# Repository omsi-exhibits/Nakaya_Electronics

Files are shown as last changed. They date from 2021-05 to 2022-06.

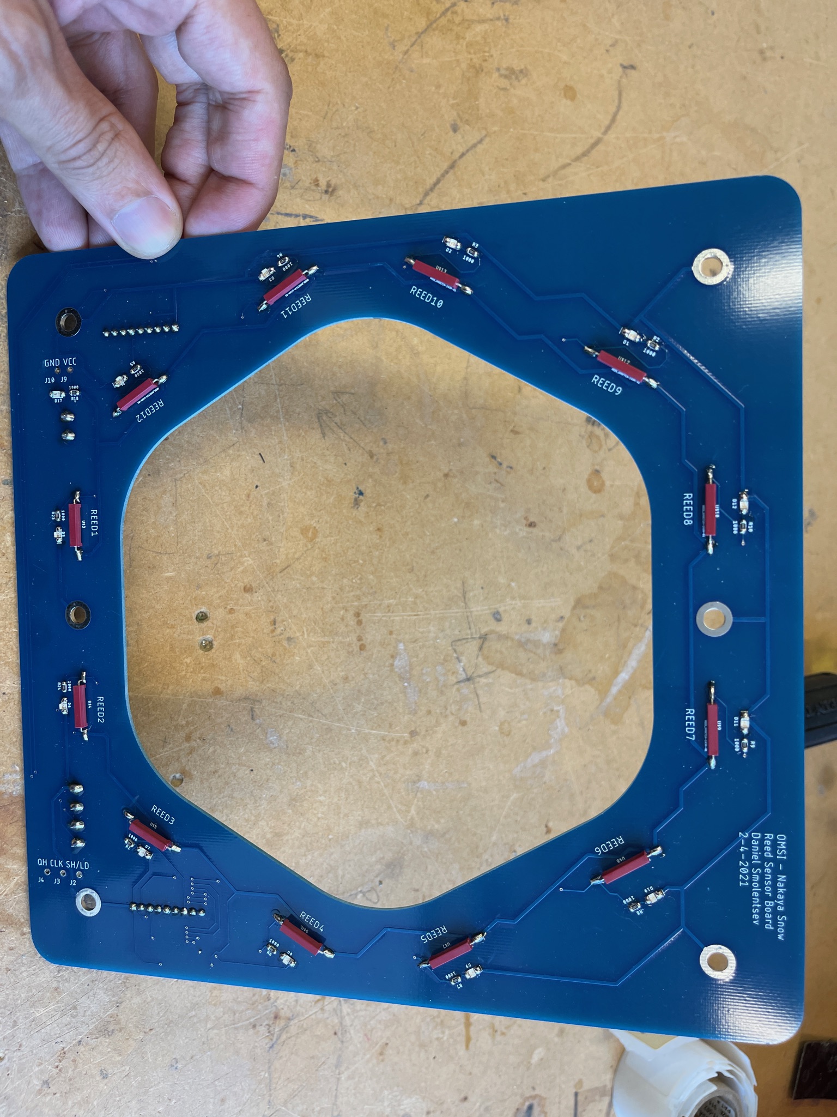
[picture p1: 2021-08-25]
docs/Electronics Pictures/IMG_0014.JPG

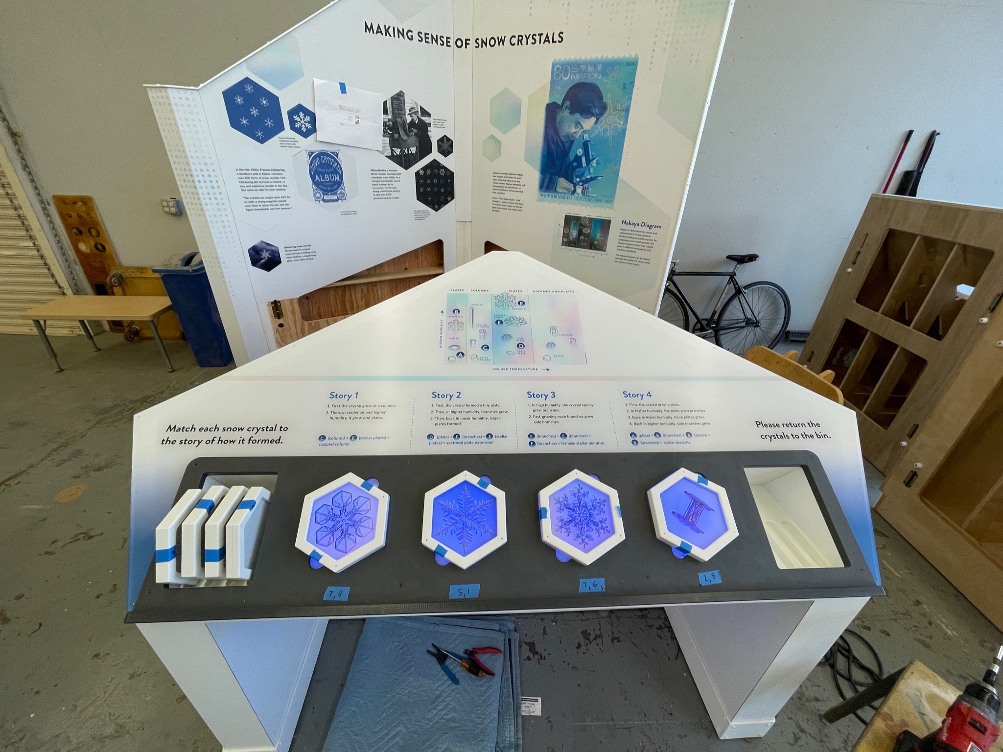
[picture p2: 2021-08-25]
docs/Electronics Pictures/IMG_0001.JPG

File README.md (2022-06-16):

# Nakaya Electronics Details

## Theory of Operation
The Nakaya Electronics are composed of a mainboard that a ItsyBitsy32u4 microcontroller is socketed into. The mainboard connects to 4 sensor boards and 4 led light boards. Each Sensor board has 12 reed switches that are read by 2 shift in registers.  Each light board has a 24 rgbw neoPixel ring attached. The software for the microcontroller checks each Sensor board for the snow pucks that correspond as a correct answer to the description of the snow for that section. Each section has 2 answers that work. When a correct answer is placed in the slot the light board fades in a light in the center of the snowflake and the mainboard triggers a sound. When the piece is removed the light fades out.  

The way the software works is that there are Sensor object instances that each loop read the sensor data store it in a data object
and then there is some logic that checks wether or not a correct sensor has been just places or has been just removed. This in turn
calls the led modules trigger functions that begin fading in or fading out.
The same logic is also responsible to trigger sounds
to play when the pieces are inserted or removed. If all 4 of the same type of snowflake are in the correct slots a victory sound will play.

### Updating software
The software is built using platformio. You can use Arduino IDE by copying the src folder
and renaming it to Nakaya and renaming the main.cpp file to Nakaya.ino. This will allow
you to use Arduino to make modifications. You will need to install any missing libraries
through the Arduino Library manager.

### Project File Organization
- docs : documentation and pictures
- src : source code
- eagle : pcb files
- examples_tests : code to help test and trouble shoot
- audio_assets : wavTrigger files
- readme.md : basic project info its the file you are reading
- docs/Nakaya BOM v2.xls (BOM is on sheet 2)
- some other directories are used by platformio and vscode

### Sensor Board
 10” by 10” square board size, sensing distance at 5/8" and less. 
- Shift Register x 2
- Reed Switches
- Phoenix Connectors
- Spacers - Between board and Milkplex
- Stand Offs - Between board and bottom plate

## Main board
- reverse voltage protection
- phoenix connectors
- MCU is Adafruit ItsyBitsy32u4

### Audio 
The wavTrigger is the audio player that interfaces with the main board via a 5pin rectangular connector. KK254 series molex connector.
This connector carries a serial signal over TX and RX lines. The connector also has 5v and gnd to power the board. The wavTrigger needs a pad solder birdged to allow for power intake from the serial input connector.

Software wise an AudioOut object is used to trigger sounds from the main code. It has a private instance of wavTrigger that is the hardware module that
plays wav files. The wavTrigger library has a line un-commented to allow interfacing via the hardware Serial1. The audio files are stereo wav files. 

### Game Pieces
- Each set will have 8 game pucks. Each game puck will have 1 more magnet then the
previous piece. So 1 + 2 +3 +4 +5 +6 +7 +8 = 36 magnets per set.
3 sets total = 108 magnets.
- The sensors count how many magnets are in the game piece to determine what
piece they are. 
- Each Sensor section can have 2 corresponding game pieces that trigger a success animation.

## Shift Registers

74hc165 inputs are enabled by a low level at the shift/load input.
clocking is accomplished by a low-to-high transition of the clock (CLK) input
while SH/LD is held high, and CLK INH is held low. (In my design CLK INH is
tied to ground via a trace)

Parallel load is inhibited when SH/LD is held high. While SH/LD is low the parallel
inputs to the register are enabled.

The SN74HC165 I am using needs clock to pulse from LOW to HIGH. Opposite of arduino
shiftIn().

### The Minimal Viable Product functions
- Scan the sensors every timeStep interval & insert results into DataObject
- Update Data that holds sensor results
- Run logic on Data 
- - If a corresponding puck is detected, Trigger LedModule leds to FadeIn
- - If puck is removed since lastStep Trigger LedModule leds to FadeOut

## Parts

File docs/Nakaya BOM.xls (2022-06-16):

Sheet: Bom
Project Name: Nakaya | Electronics
 | Bill of Materials
ITEM | DESCRIPTION | Qty/Unit | QTY Total | UNIT PRICE | SUBTOTAL | Link | Notes
Microcontroller | Adafruit itsybitsy 32u4 5v 16mhz | 1 | 2 | $9.95 | $19.90 | https://www.digikey.com/short/zjwf45 | Ordered
5v Power Supply | LRS-75-5 5V 14A – Can power the Mainboard as well as the 4 led ring holder boards and the 4 sensor boards. | 1 |  | $18.16 |  | https://www.digikey.com/en/products/detail/mean-well-usa-inc/LRS-75-5/7705056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
LED Rings | Neopixel 24 RGBW Natural white (1.5A per ring on full brightness) | 4 | 7 | $19.99 | $139.93 | https://www.digikey.com/en/products/detail/adafruit-industries-llc/2862/5878439 | Ordered
Custom PCB |  |  | 1 | $50.00 | $50.00
PCB enclosure | From aliexpress - ~1month shipping AK-P-25 PLC – set of 4 |  | 1 | $35.33 | $35.33 | https://www.aliexpress.com/item/32868993859.html | Ordered 9-15ish-20
PCB components (Estimate) |  |  | 1 | $100.00 | $100.00
 |  |  |  |  | $325.26

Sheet: PCB BOM
Project Name: SNOW Nakaya Sensor Board | Ver 2 | Updated 5/20/21 |  | Electronics
 |  |  |  | PCB Bill of Materials
ITEM | Designator | Value | Part Num | DESCRIPTION | Qty/Unit | QTY Total | UNIT PRICE | SUBTOTAL | Link | Purchase State | Notes | Alternate Part
Reverse Polarity Protection Pch Mosfet | Q5, Q6 | TSM7P06CP | TSM7P06CP | MOSFET -60V, -7A, Single P-Channel Power MOSFET | 2
Power Connector Header | X2 | na | 1755736 | TERM BLOCK HDR 2POS STR 5.08MM | 1 | 4 |  |  | https://www.digikey.com/en/products/detail/phoenix-contact/1755736/260518
Power Connector Plug | na | na | 1792757 | TERM BLOCK PLUG 2POS STR 5.08MM | 1 | 4 |  |  | https://www.digikey.com/en/products/detail/phoenix-contact/1792757/260430
LED Power Indicator | D17 | na | LTST-C150KRKT | Red SMD LED 1206 | 1 | 4 |  |  | https://www.digikey.com/en/products/detail/lite-on-inc/LTST-C150KRKT/386761
LED Indicator for Reed Switches | D1, D2, D3, D4, D5, D6, D7, D8, D9, D10, D11, D12 | na | LTST-C230TBKT | Blue SMD LED 1206 | 12 | 48 |  |  | https://www.digikey.com/en/products/detail/lite-on-inc/LTST-C230TBKT/388531
Connector Shift Register Header | X1 | na | 1755752 | TERM BLOCK HDR 4POS STR 5.08MM | 1 | 4 |  |  | https://www.digikey.com/en/products/detail/phoenix-contact/1755752/260520 |  |  | https://www.digikey.com/en/products/detail/phoenix-contact/1912841/2511826
Connector Shift Register Plug | na | na | 1792773 |  |  | 4 |  |  | https://www.digikey.com/en/products/detail/phoenix-contact/1792773/260432
Reed Switch | U$3, U$4, U$5, U$6, U$7, U$8, U$9, U$10, U$12, U$13, U$14, U$15 | CT10-1040-G1 | CT10-1040-G1 | SPST-NO 10 ~ 40AT Operate Range 10W 500mA (AC/DC) 140 V | 12 | 48 |  |  | https://www.digikey.com/en/products/detail/coto-technology/CT10-1040-G1/4794935
Shift Register IC | U$1, U$11 | SPARKFUN-DIGITALIC_74165D | SN74HC165D | IC 8-BIT SHIFT REGISTER 16-SOIC | 2 | 8 |  |  | https://www.digikey.com/en/products/detail/texas-instruments/SN74HC165D/376951
Resistor 9SIP Array 10k Pull down for Shift Registers | 4610X-1-103LF-ND1 | 600 | Omsi Stock | RES ARRAY 8 RES 10K OHM 9SIP | 2 | 4 |  |  | https://www.digikey.com/en/products/detail/bourns-inc/4609X-AP1-103LF/3741069
Resistor Current Limiting for LEDS | R3, R6, R8, R11, R13, R15 | 1K |  | Resistor 0805 | 12 |  |  |  | https://www.digikey.com/en/products/detail/panasonic-electronic-components/ERJ-6GEYJ102V/83014
Capacitor for Shift Register IC | C4, C5 | 1UF | CL21B105KAFVPNE | CAP CER 1UF 25V X7R 0805 | 2 |  |  |  | https://www.digikey.com/en/products/detail/samsung-electro-mechanics/CL21B105KAFVPNE/5961306

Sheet: Change notes
 | Bom changes
Date | Note
2021-05-20 | Changed reedswitch because it was out of stock
 | Changed Bluee LED because it was out of stock
 | Corrected the 4 pin connector to be 270 degerees rotated

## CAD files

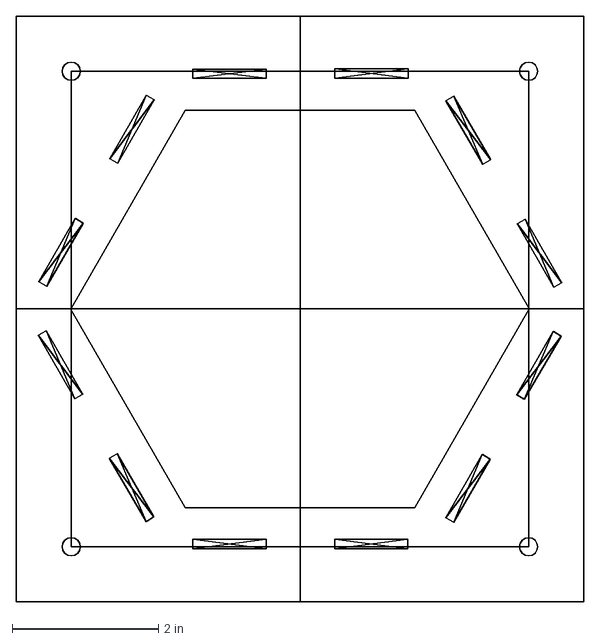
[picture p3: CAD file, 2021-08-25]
docs/Sensor Locations.dxf
7.75 x 8.00 in

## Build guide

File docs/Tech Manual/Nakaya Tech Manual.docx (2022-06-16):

Theory of Operation

The Nakaya Electronics are composed of a mainboard that has a ItsyBitsy32u4 microcontroller socketed into. The mainboard connects to 4 sensor boards and 4 led light boards. Each Sensor board has 12 reed switches that are read by 2 shift-in registers. Each light board has a 24 rgbw neoPixel ring attached. The software for the microcontroller checks each Sensor board for the snow pucks that correspond as a correct answer to the description of the snow for that section. Each section has 2 answers that work. When a correct answer is placed in the slot the light board fades in a light in the center of the snowflake and the mainboard triggers a sound. When the piece is removed the light fades out.

Parts list

Description | Serves/Location | Part # | Vendor | Quantity
ItsyBitsy 5v 16Mhz | Microcontroller for main pcb | 3677 | Digikey | 1
Wav Trigger | Plays Audio Sounds | 1568-1115-ND | Digikey | 1
SanDisk 16GB microSDHC | Holds wav audio files | SDSQUAR-016G-GN6MA | Amazon | 1
Kinter k3118 | Audio Amplifier | k3118 | Amazon | 1
DPI 4" waterproof speaker | Plays sounds | DPI-60B | Amazon | 1
Meanwell 5v 14a PSU * | Power supply for electronics | LRS-75-5 | Digikey | 1
Neopixel RGBW 24 LED ring | Led light for puck slots | 2862 | Digikey | 4

Troubleshooting

The unit is not powering on. | 1) Verify that the power strip switch is in the on position. 2) Verify the main board inside the beige enclosure is receiving power. It has a red power led that will be lit. 3) Verify that the power cable wires are firmly connected to the green phoenix connector screw terminals.
Led light is not lighting up when a correct puck is inserted into its corresponding slot, but audio sound plays. | 1 ) Try reseating the connections on that sensor board and the main board. 2) Verify that those connectors have their wires firmly connected to the screw terminals. The phoenix connectors on the sensor boards can be removed by pulling them straight down.

The audio is not being played when a correct puck is inserted into its corresponding slot

1) Check to make sure the power supply for the amp is firmly plugged into the power strip. The amp will glow blue when it has power and is on.

2) Check to make sure the kinter amp is on and the volume is not all the way down. The big knob is the volume knob.

2) Check to make sure the white rectangular connector in the center of the mainboard is plugged in all the way.

3) Check to make sure that the rectangular connector on the wav Trigger is plugged in all the way. Through this connector the wav Trigger receives power and data.

4) Check that the 3.5mm aux cable is plugged in all the way into the wav trigger and the kinter amp.
The volume is too quiet or too loud | 1) Inside the cabinet is a kinter amp. The amp has a big knob with a blue led around it. This knob can be used to adjust the volume.

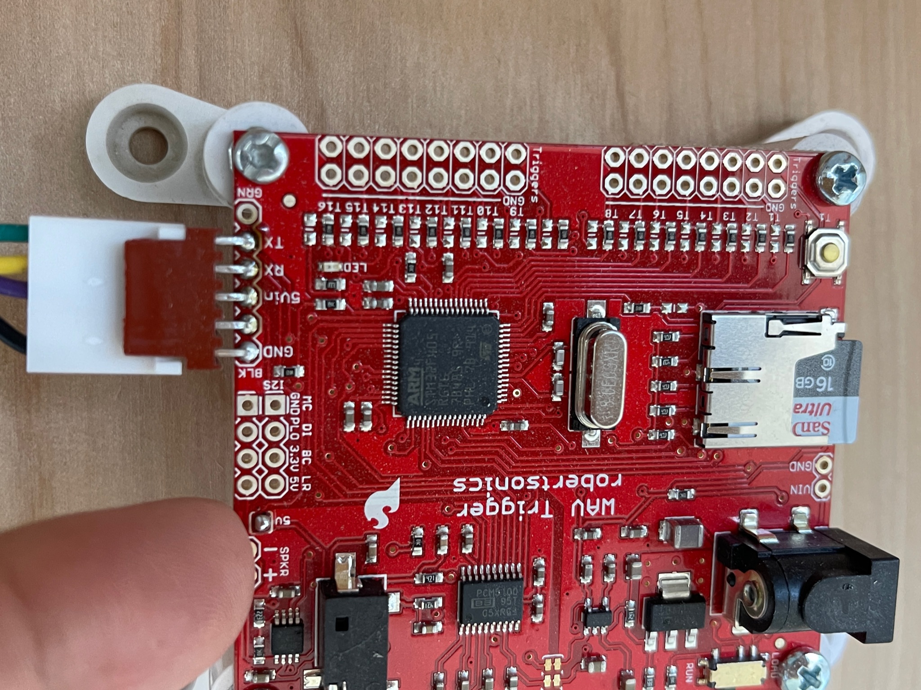
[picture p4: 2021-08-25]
docs/Electronics Pictures/solder_here_wavTrigger.JPG

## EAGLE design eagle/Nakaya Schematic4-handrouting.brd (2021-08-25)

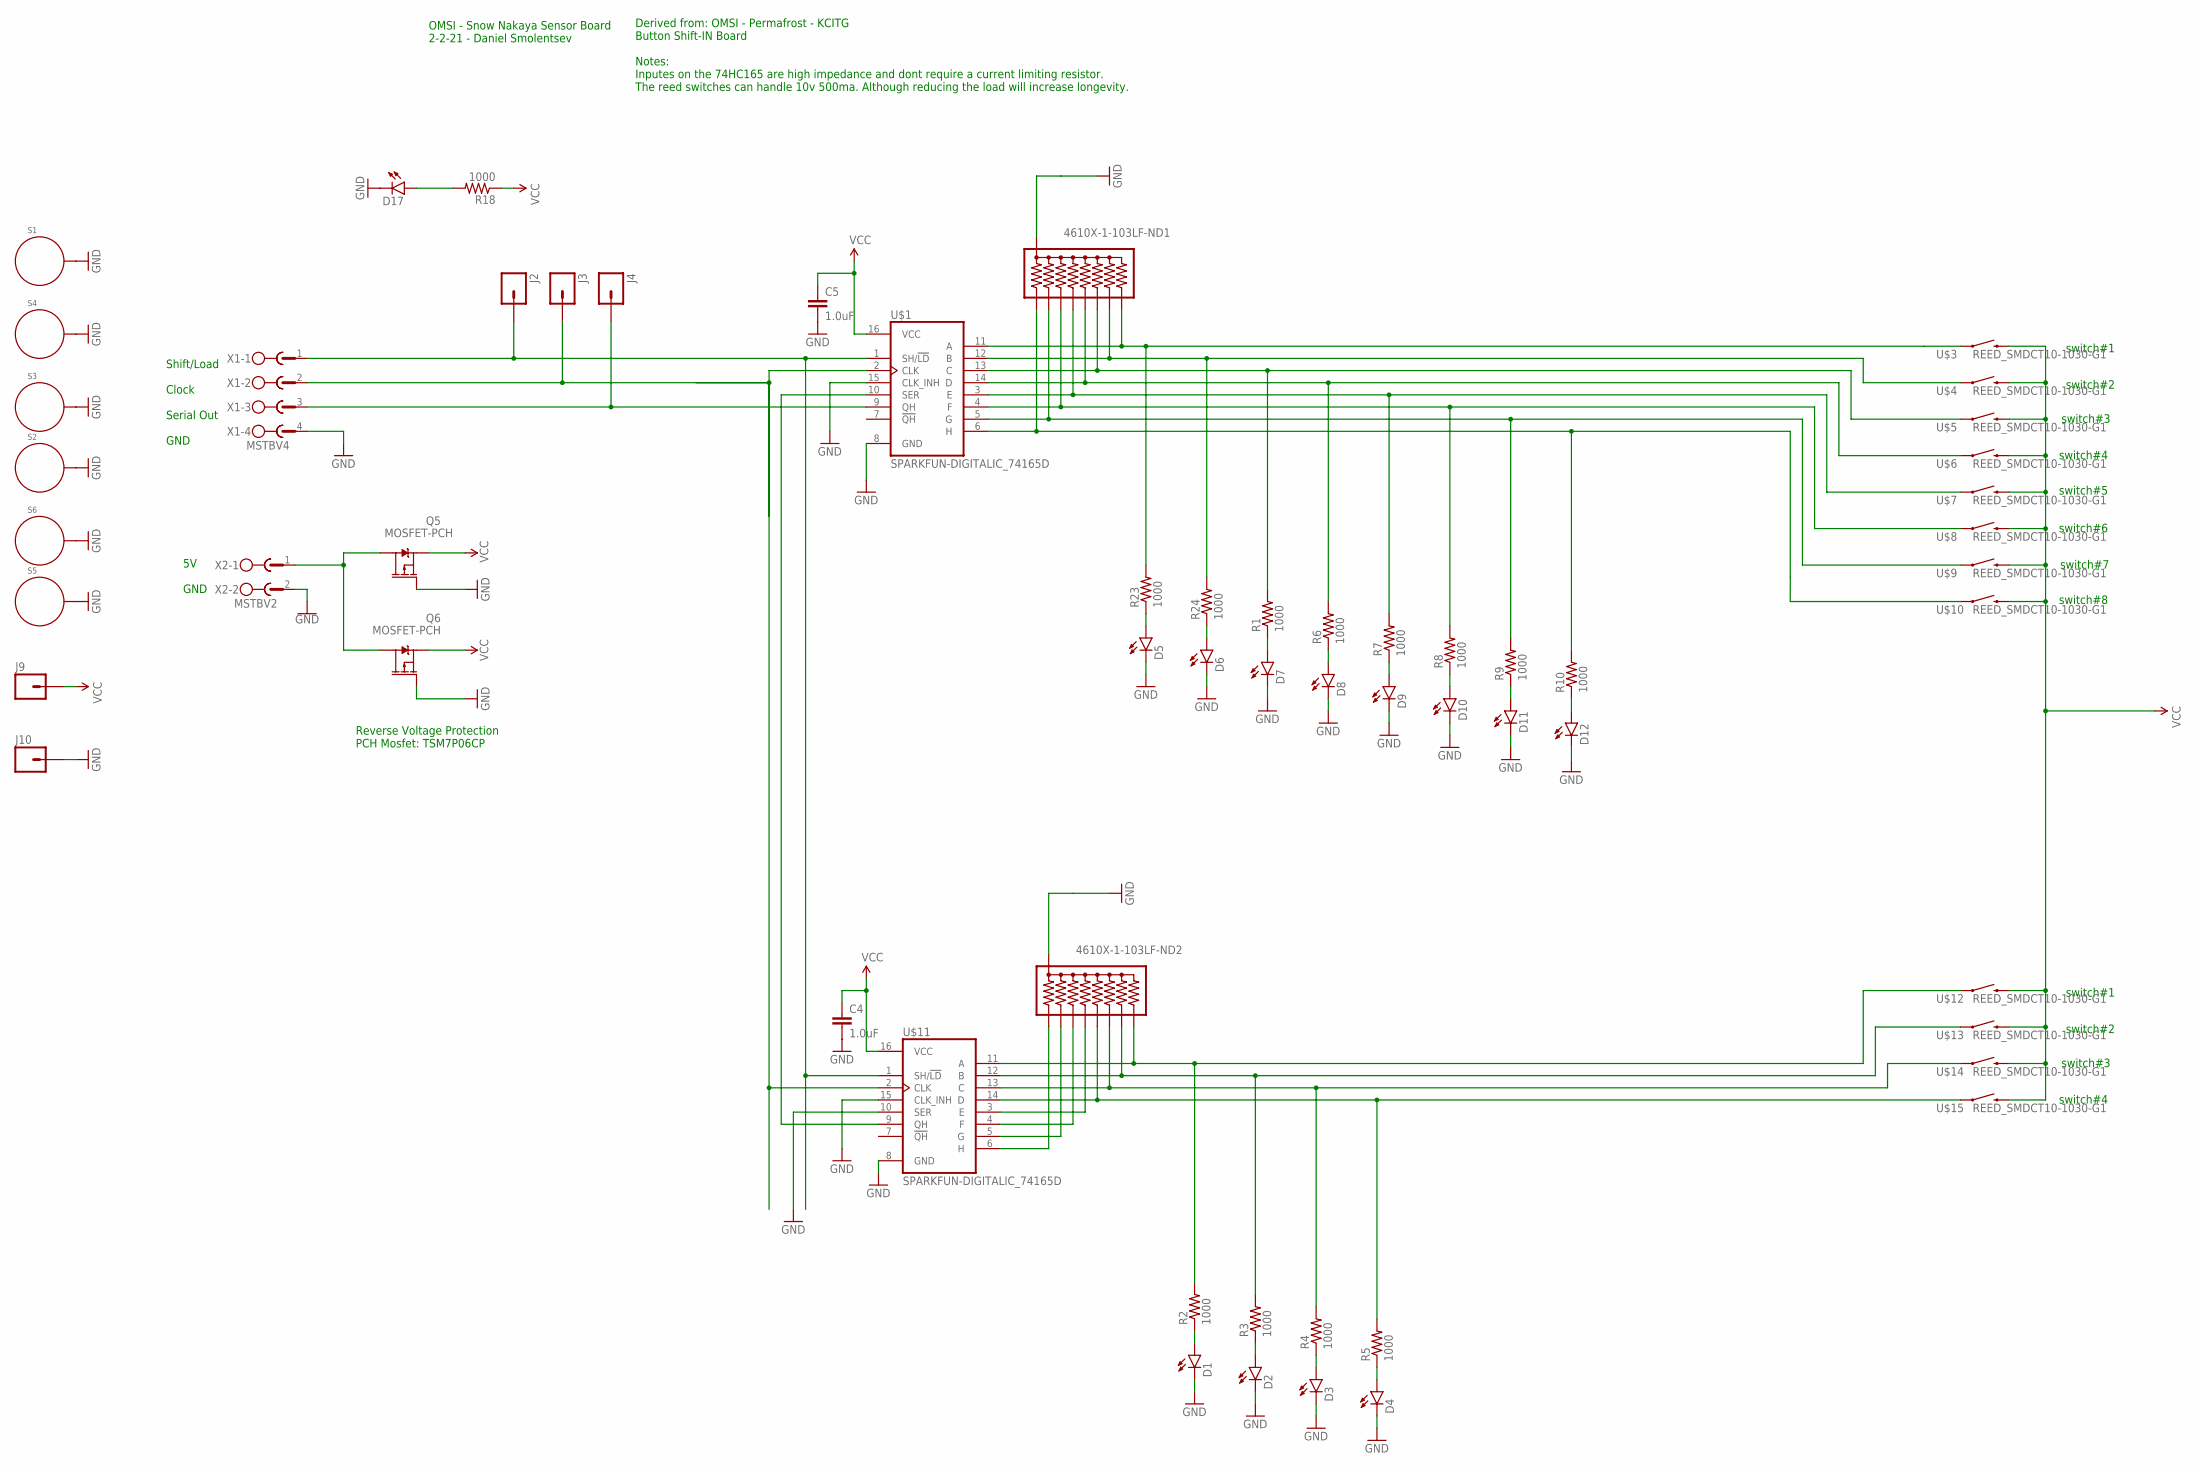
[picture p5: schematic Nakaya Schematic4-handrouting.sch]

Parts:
4610X-1-103LF-ND1, 4610X-1-103LF-ND2: RPACK-BUSSED-8-SIP-PTH-8; RPACK-SIP-PTH-8
C4, C5: 1.0uF; SPARKFUN-CAPACITORS_0805
D1, D2, D3, D4, D5, D6, D7, D8, D9, D10, D11, D12, D17: SPARKFUN-LED_LED1206; SPARKFUN-LED_LED-1206
J2, J3, J4, J9, J10: SPARKFUN-CONNECTORS_M01PTH_NO_SILK_YES_STOP; SPARKFUN-CONNECTORS_1X01_NO_SILK
Q5, Q6: MOSFET-PCH; DPAK
R1, R2, R3, R4, R5, R6, R7, R8, R9, R10, R18, R23, R24: 1000; SPARKFUN-PASSIVES_0805:1
S1, S2, S3, S4, S5, S6: STANDOFF_ELECTRICAL.18"; STANDOFF_ELECTRIC_#8_OVERSIZED
U$1, U$11: SPARKFUN-DIGITALIC_74165D; SPARKFUN-DIGITALIC_SO16
U$3, U$4, U$5, U$6, U$7, U$8, U$9, U$10, U$12, U$13, U$14, U$15: REED_SMDCT10-1030-G1; REED_SMD_2
X1: MSTBV4
X2: MSTBV2

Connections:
CLK: J3.1, U$1.2 (CLK), U$11.2 (CLK), X1.2
GND: 4610X-1-103LF-ND1.P$1 (1), 4610X-1-103LF-ND2.P$1 (1), C4.2, C5.2, D1.C, D2.C, D3.C, D4.C, D5.C, D6.C, D7.C, D8.C, D9.C, D10.C, D11.C, D12.C, D17.C, J10.1, Q5.1 (G), Q6.1 (G), S1.P$1, S2.P$1, S3.P$1, S4.P$1, S5.P$1, S6.P$1, U$1.8 (GND), U$1.15 (CLK_INH), U$11.8 (GND), U$11.10 (SER), U$11.15 (CLK_INH), X1.4, X2.2
LD: J2.1, U$1.1 (SH/!LD), U$11.1 (SH/!LD), X1.1
unnamed: 4610X-1-103LF-ND2.P$7 (7), R4.2, U$11.13 (C), U$14.3 (1)
unnamed: 4610X-1-103LF-ND2.P$6 (6), R5.2, U$11.14 (D), U$15.3 (1)
unnamed: D17.A, R18.2
unnamed: 4610X-1-103LF-ND1.P$4 (4), R8.2, U$1.4 (F), U$8.3 (1)
unnamed: Q5.4 (D), Q6.4 (D), X2.1
unnamed: 4610X-1-103LF-ND1.P$3 (3), R9.2, U$1.5 (G), U$9.3 (1)
unnamed: 4610X-1-103LF-ND1.P$2 (2), R10.2, U$1.6 (H), U$10.3 (1)
unnamed: D5.A, R23.1
unnamed: 4610X-1-103LF-ND2.P$8 (8), R3.2, U$11.12 (B), U$13.3 (1)
unnamed: D7.A, R1.1
unnamed: D6.A, R24.1
unnamed: D1.A, R2.1
unnamed: D8.A, R6.1
unnamed: D2.A, R3.1
unnamed: 4610X-1-103LF-ND2.P$9 (9), R2.2, U$11.11 (A), U$12.3 (1)
unnamed: D3.A, R4.1
unnamed: D4.A, R5.1
unnamed: D9.A, R7.1
unnamed: 4610X-1-103LF-ND2.P$5 (5), U$11.3 (E)
unnamed: 4610X-1-103LF-ND2.P$4 (4), U$11.4 (F)
unnamed: 4610X-1-103LF-ND2.P$3 (3), U$11.5 (G)
unnamed: D10.A, R8.1
unnamed: 4610X-1-103LF-ND2.P$2 (2), U$11.6 (H)
unnamed: D11.A, R9.1
unnamed: D12.A, R10.1
unnamed: 4610X-1-103LF-ND1.P$9 (9), R23.2, U$1.11 (A), U$3.3 (1)
unnamed: 4610X-1-103LF-ND1.P$8 (8), R24.2, U$1.12 (B), U$4.3 (1)
unnamed: 4610X-1-103LF-ND1.P$7 (7), R1.2, U$1.13 (C), U$5.3 (1)
unnamed: 4610X-1-103LF-ND1.P$6 (6), R6.2, U$1.14 (D), U$6.3 (1)
unnamed: 4610X-1-103LF-ND1.P$5 (5), R7.2, U$1.3 (E), U$7.3 (1)
QH: J4.1, U$1.9 (QH), X1.3
SER: U$1.10 (SER), U$11.9 (QH)
VCC: C4.1, C5.1, J9.1, Q5.3 (S), Q6.3 (S), R18.1, U$1.16 (VCC), U$3.4 (2), U$4.4 (2), U$5.4 (2), U$6.4 (2), U$7.4 (2), U$8.4 (2), U$9.4 (2), U$10.4 (2), U$11.16 (VCC), U$12.4 (2), U$13.4 (2), U$14.4 (2), U$15.4 (2)

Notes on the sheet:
Derived from: OMSI - Permafrost - KCITG Button Shift-IN Board Notes: Inputes on the 74HC165 are high impedance and dont require a current limiting resistor. The reed switches can handle 10v 500ma. Although reducing the load will increase longevity.
switch#1
switch#2
switch#3
switch#4
switch#5
switch#6
switch#7
switch#8
Shift/Load Clock Serial Out GND
Reverse Voltage Protection PCH Mosfet: TSM7P06CP
5V GND
OMSI - Snow Nakaya Sensor Board 2-2-21 - Daniel Smolentsev

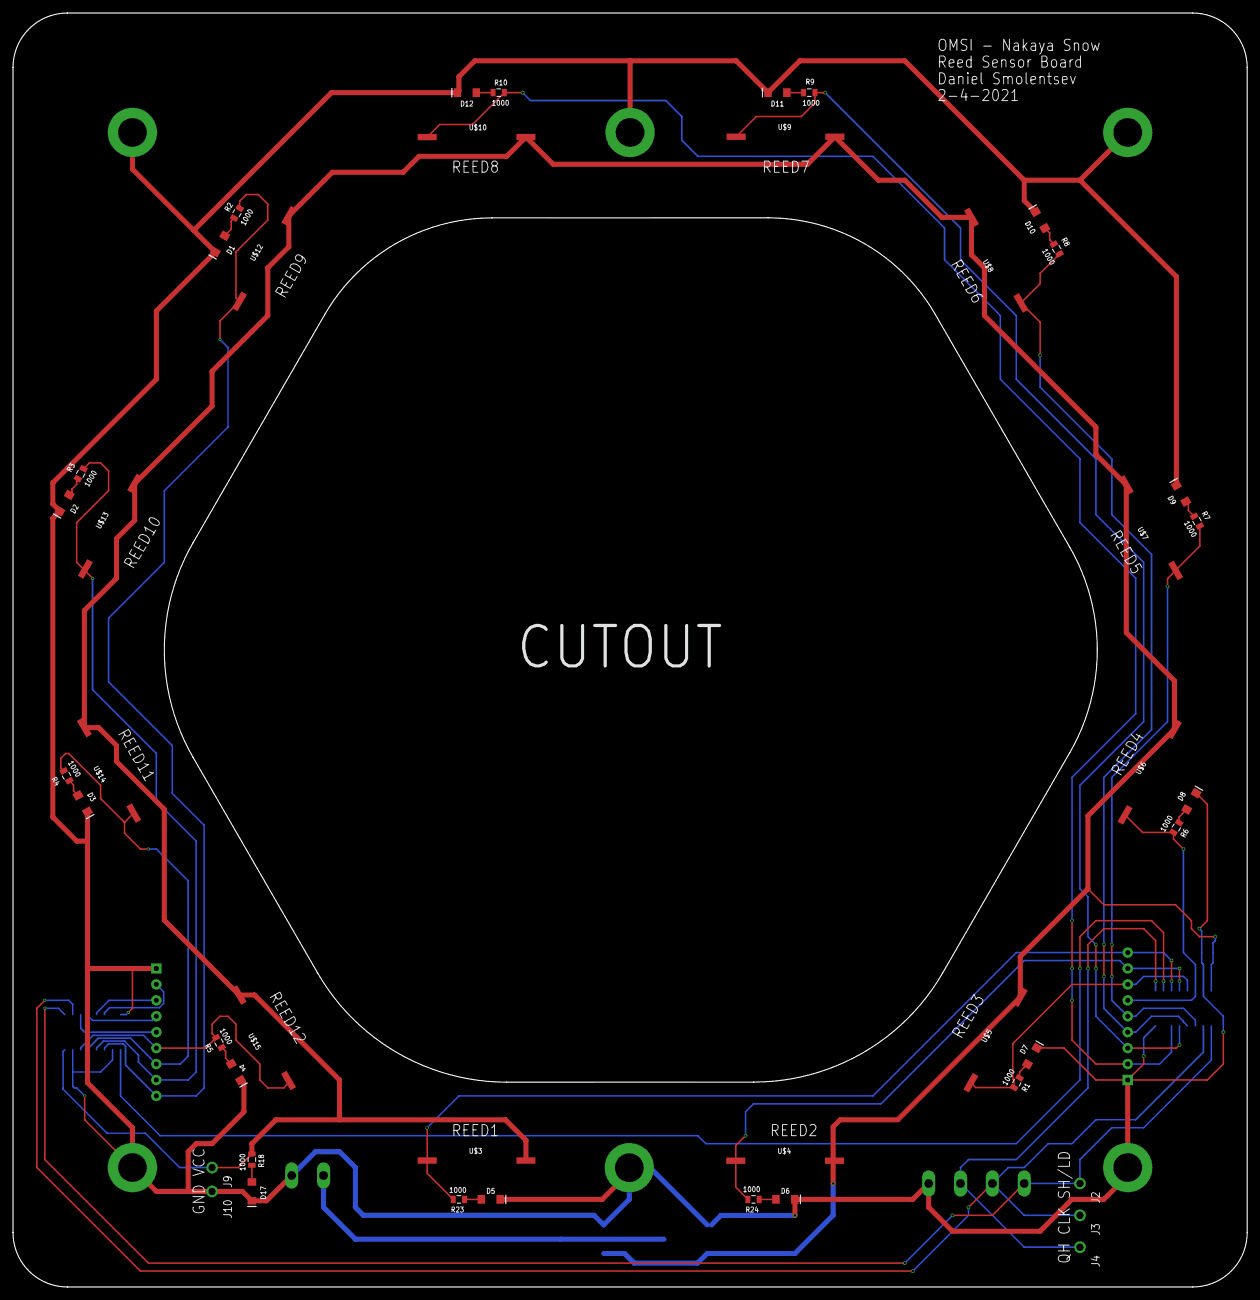
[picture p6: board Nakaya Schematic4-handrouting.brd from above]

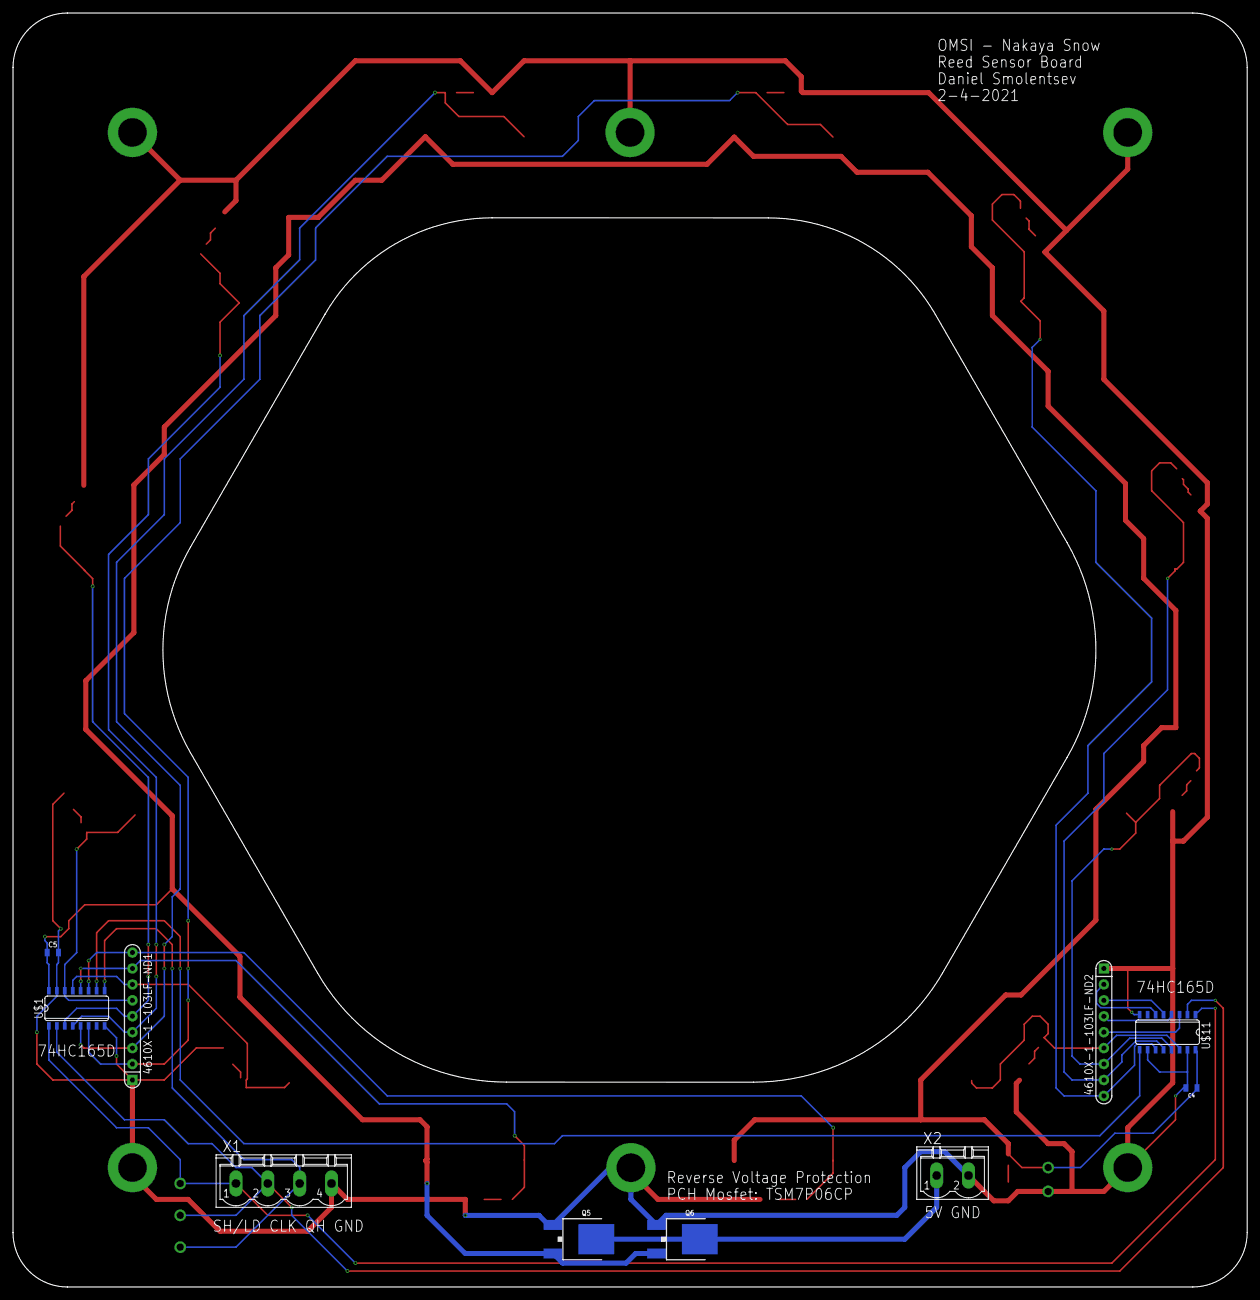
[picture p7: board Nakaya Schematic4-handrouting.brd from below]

Board: 2 copper layers, 196.8 x 203.2 mm, 59 parts (10 on the bottom side), 36 nets.

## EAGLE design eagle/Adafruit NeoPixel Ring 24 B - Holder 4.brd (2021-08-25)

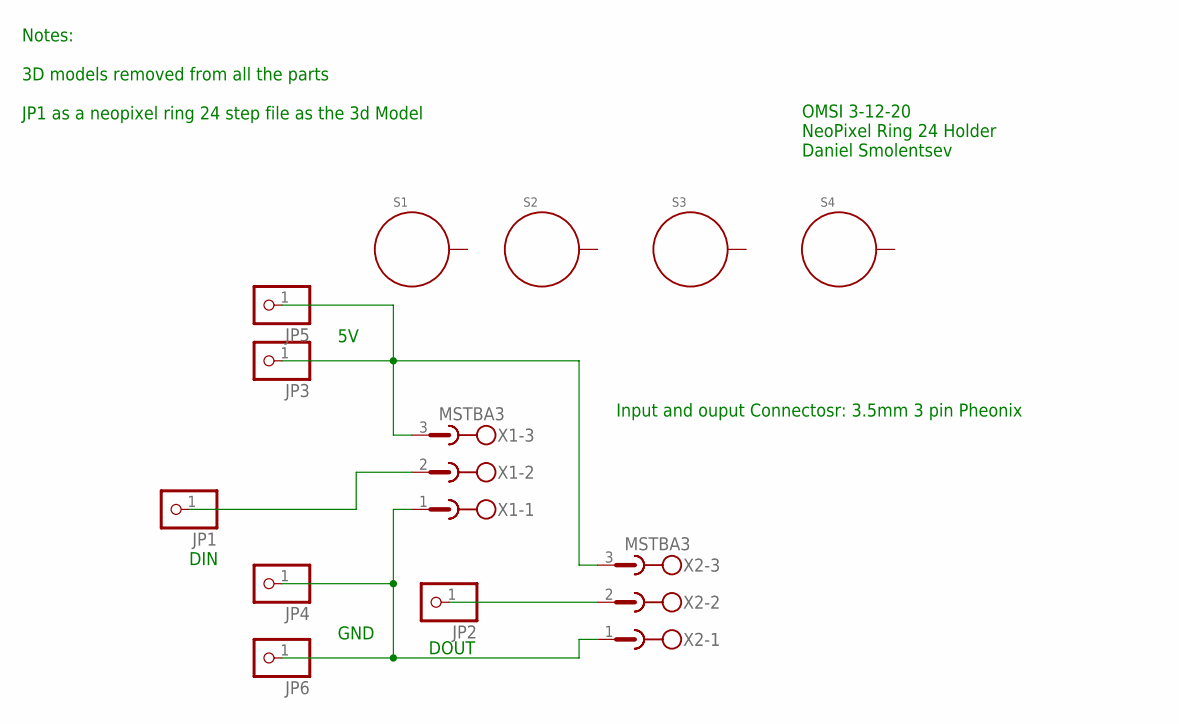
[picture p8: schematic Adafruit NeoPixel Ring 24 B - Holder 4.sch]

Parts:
JP1, JP2, JP3, JP4, JP5, JP6: PINHD-1X1CB; 1X01-CLEANBIG
S1, S2, S3, S4: STANDOFF_ELECTRICAL.17"; STANDOFF-ELECTRICAL
X1, X2: MSTBA3

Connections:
5V: JP3.1, JP5.1, X1.3, X2.3
DIN: JP1.1, X1.2
GND: JP4.1, JP6.1, X1.1, X2.1
unnamed: JP2.1, X2.2

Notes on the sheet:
GND
DIN
DOUT
Input and ouput Connectosr: 3.5mm 3 pin Pheonix
OMSI 3-12-20 NeoPixel Ring 24 Holder Daniel Smolentsev
Notes: 3D models removed from all the parts JP1 as a neopixel ring 24 step file as the 3d Model

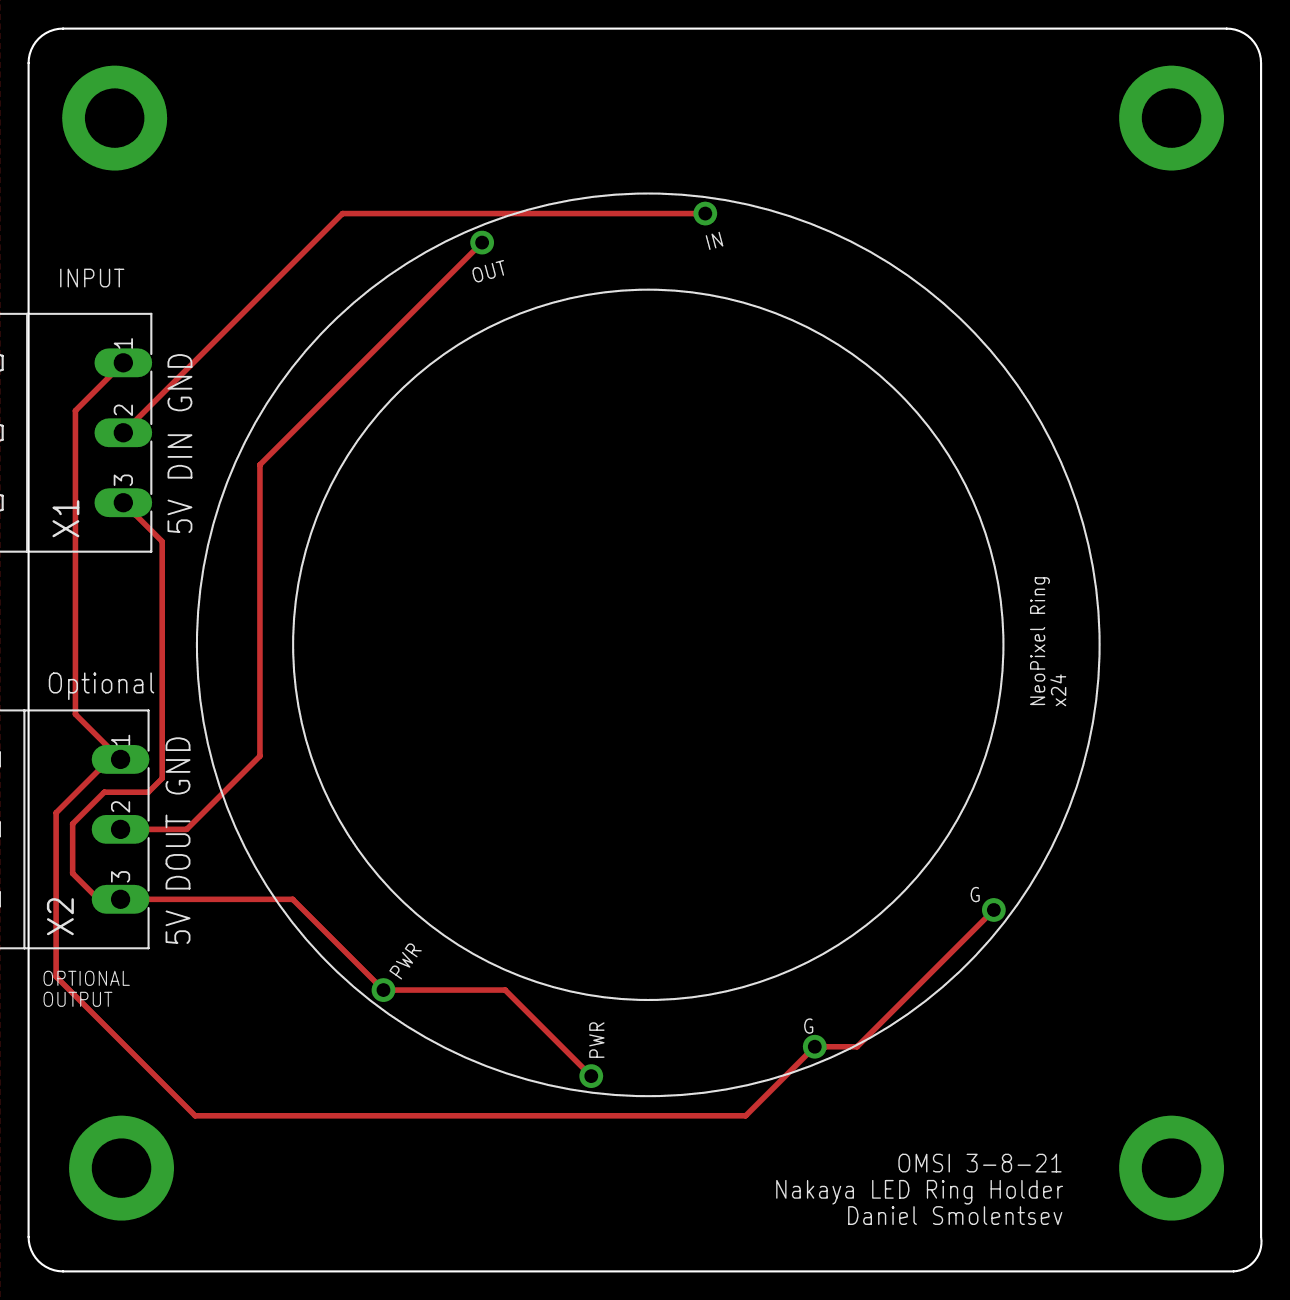
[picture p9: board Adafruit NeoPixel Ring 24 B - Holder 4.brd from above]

Board: 2 copper layers, 89.5 x 90.2 mm, 12 parts (0 on the bottom side), 4 nets.

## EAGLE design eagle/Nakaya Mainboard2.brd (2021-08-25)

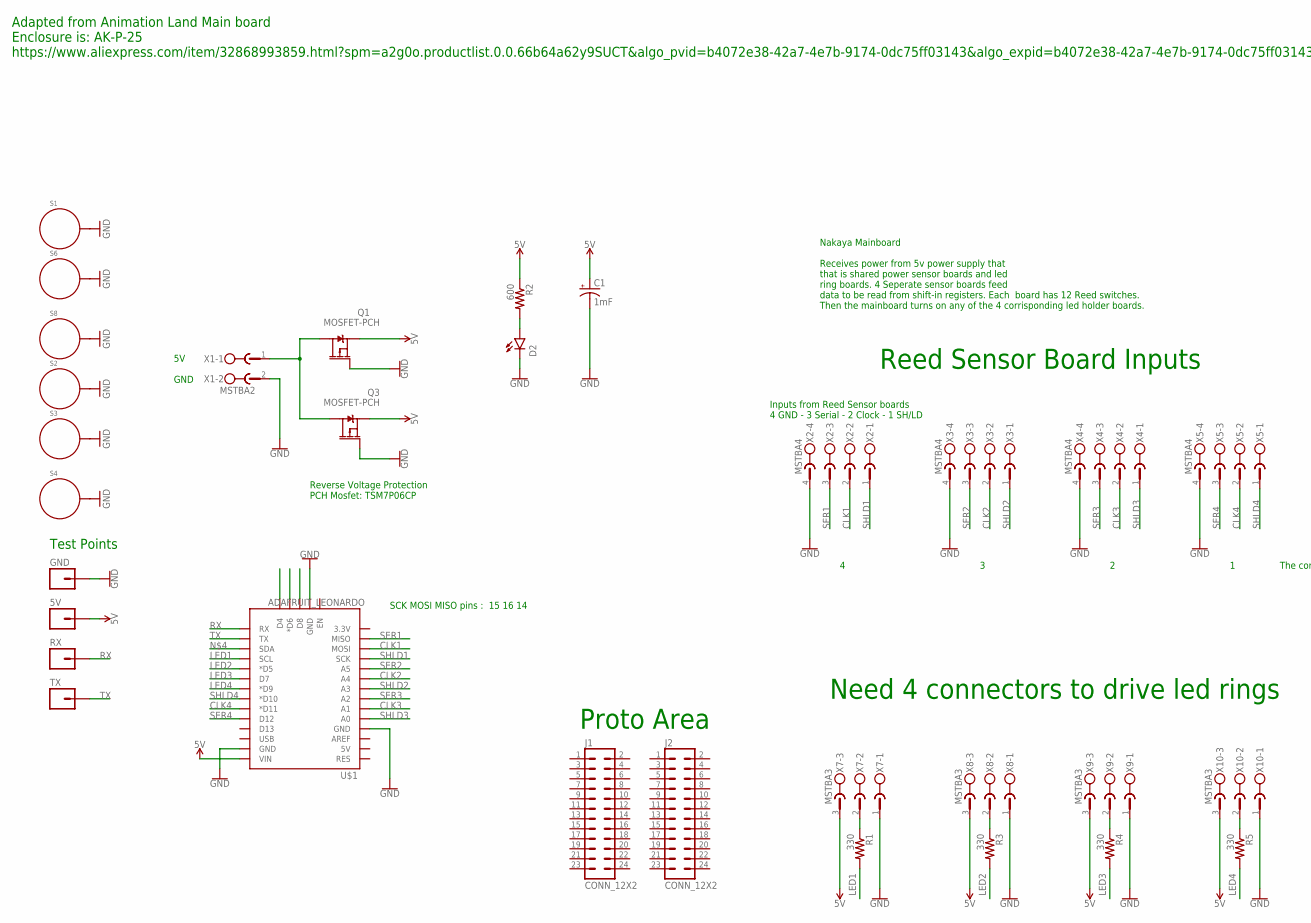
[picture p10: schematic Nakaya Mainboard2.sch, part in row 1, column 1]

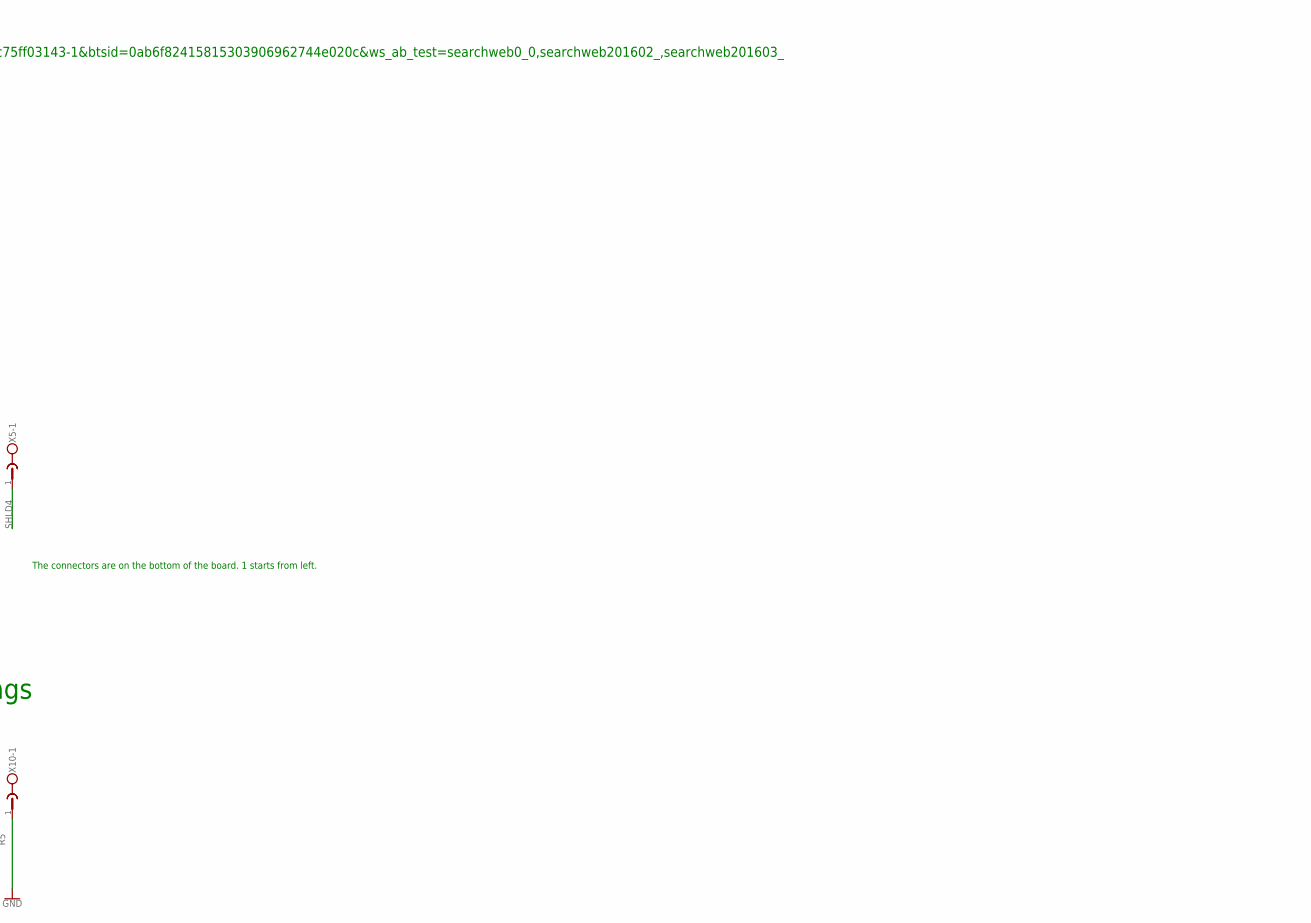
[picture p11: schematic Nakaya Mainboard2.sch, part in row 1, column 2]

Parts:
5V: M01PTH; 1X01
C1: 1mF; CPOL-RADIAL-5MM-10MM
D2: RED; SPARKFUN-LED_LED-1206
GND: M01PTH; 1X01
J1, J2: CONN_12X2; 2X12
Q1, Q3: MOSFET-PCH; DPAK
R1, R3, R4, R5: 330; R0805
R2: 600; R0805
RX: M01PTH; 1X01
S1, S2, S3, S4, S6, S8: STANDOFF_ELECTRICAL5-32; STANDOFF_ELECTRICAL_5_32
TX: M01PTH; 1X01
U$1: ADAFRUIT_LEONARDO; ADAFRUIT_LENOARDO
X1: MSTBA2
X2, X3, X4, X5: MSTBA4
X7, X8, X9, X10: MSTBA3

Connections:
5V: 5V.1, C1.+, Q1.3 (S), Q3.3 (S), R2.1, U$1.VIN, X7.3, X8.3, X9.3, X10.3
CLK1: U$1.MOSI, X2.2
CLK2: U$1.A4, X3.2
CLK3: U$1.A1, X4.2
CLK4: U$1.D11 (*D11), X5.2
GND: C1.-, D2.C, GND.1, Q1.1 (G), Q3.1 (G), S1.P1, S2.P1, S3.P1, S4.P1, S6.P1, S8.P1, U$1.GND@0 (GND), U$1.GND@1 (GND), U$1.GND@2 (GND), X1.2, X2.4, X3.4, X4.4, X5.4, X7.1, X8.1, X9.1, X10.1
LED1: R1.2, U$1.SCL
LED2: R3.2, U$1.D5 (*D5)
LED3: R4.2, U$1.D7
LED4: R5.2, U$1.D9 (*D9)
unnamed: D2.A, R2.2
unnamed: R1.1, X7.2
unnamed: R3.1, X8.2
unnamed: R4.1, X9.2
unnamed: R5.1, X10.2
unnamed: Q1.4 (D), Q3.4 (D), X1.1
RX: RX.1, U$1.RX
SER1: U$1.MISO, X2.3
SER2: U$1.A5, X3.3
SER3: U$1.A2, X4.3
SER4: U$1.D12, X5.3
SHLD1: U$1.SCK, X2.1
SHLD2: U$1.A3, X3.1
SHLD3: U$1.A0, X4.1
SHLD4: U$1.D10 (*D10), X5.1
TX: TX.1, U$1.TX

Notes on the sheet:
Adapted from Animation Land Main board Enclosure is: AK-P-25 https://www.aliexpress.com/item/32868993859.html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…
Nakaya Mainboard Receives power from 5v power supply that that is shared power sensor boards and led ring boards. 4 Seperate sensor boards feed data to be read from shift-in registers. Each board has 12 Reed switches. Then the mainboard turns on any of the 4 corrisponding led holder boards.
Reverse Voltage Protection PCH Mosfet: TSM7P06CP
Inputs from Reed Sensor boards 4 GND - 3 Serial - 2 Clock - 1 SH/LD
5V GND
Need 4 connectors to drive led rings
Reed Sensor Board Inputs
SCK MOSI MISO pins : 15 16 14
Proto Area
Test Points
The connectors are on the bottom of the board. 1 starts from left.

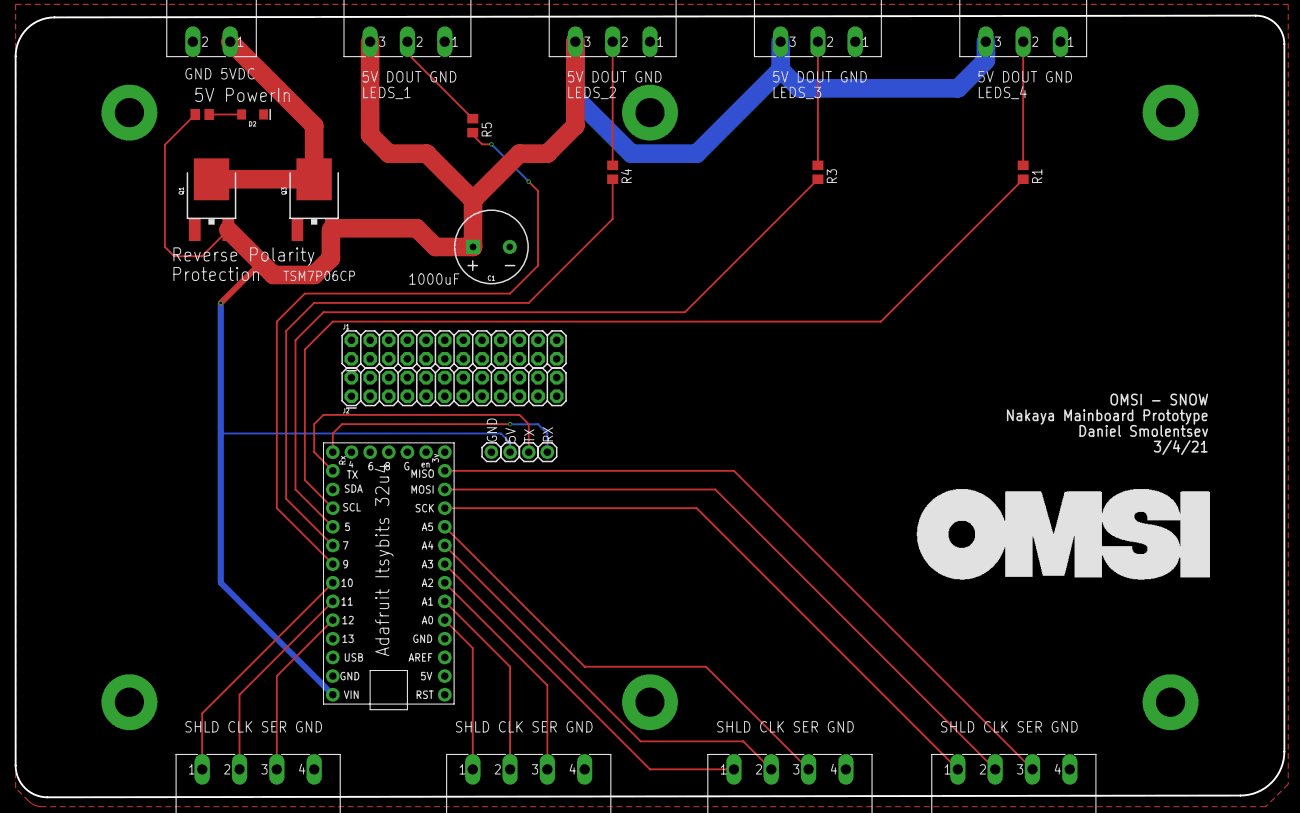
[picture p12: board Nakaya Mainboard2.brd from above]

Board: 2 copper layers, 172.7 x 106.4 mm, 31 parts (0 on the bottom side), 26 nets.

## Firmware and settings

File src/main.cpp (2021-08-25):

/* Nakaya Electronics Mainboard
 * 
 * Micro: ItsyBitys 32u4
 * 
 * The main board has 4 connections to sensor modules. Each module has
 * 2 SN74HC165 ICs to collect 12 parallel inputs from the read switches
 * and send them out as serial data. The reed switches are pulled
 * low with 10k resistors. 
 * 
 * Upon reading the correct number of magnets on the read switches the sensor board
 * will triggerFadeIn() on the corresponding ledModule
 * 
 * This project uses a simplified Model View Controller design pattern
 * The Model data is stored in the Data object. The LedModule is the view.
 * The controller code is inside the arduino loop().
 * 
 * Daniel Smolentsev
 * Last Major Update: 8/25/21
 * MVP
 */
#include <Arduino.h>
#include <Adafruit_NeoPixel.h>
#include "PuckSensor.h"
#include "LedModule.h"
#include "HeartBeat.h"
#include "Data.h"
#include "audio/AudioOut.h"
// Audio 
AudioOut audioOut;

// pin defines are stored in hw.h
#include "hw.h"
// Comment out to disable debug messages
#define DEBUG

// Declare array of Sensors and leds 
#define NUM_SENSORS 4
#define NUM_LEDMODULES 4
#define OPTIONS 2
// Puck sensor connector numbers(order) increment from right to left on the PCB so they are in descending order here
// this way in the arrays pSensor[1] and ledModules[1] correspond to the same section 
PuckSensor pSensors[NUM_SENSORS] = {PuckSensor(SER4, CLK4, SHLD4), PuckSensor(SER3, CLK3, SHLD3),PuckSensor(SER2, CLK2, SHLD2),PuckSensor(SER1, CLK1, SHLD1)};
LedModule ledModules[NUM_LEDMODULES] = {LedModule(LEDPIN1, NUMLEDS), LedModule(LEDPIN2, NUMLEDS),LedModule(LEDPIN3, NUMLEDS), LedModule(LEDPIN4, NUMLEDS)};

// array of arrays of correct pucks to look for per sensor slot
int correctPucks[NUM_SENSORS][OPTIONS] = { {6,2}, {5,1}, {7,3}, {8,4} };

// These timers used to wait for the puck to be fully inserted before checking if it is the correct one
// because on insertion multiple puck sensor readings are triggered and need to be ignored until after the cooldown
unsigned long successCooldownTimers[NUM_SENSORS] = {0,0,0,0};
unsigned long removeCooldownTimers[NUM_SENSORS] = {0,0,0,0};

// PUCK_COOLDOWN is the delay to wait before check wether the correct puck has been inserted and playing the audio feedback.
#define PUCK_COOLDOWN 700

// When all 4 slots have the correct puck inserted and its of the same set
// the coresponding bool array will be all true and a victory sound will play
bool bentleyInSlots[NUM_SENSORS] = {false, false, false, false};
bool libbrechtInSlots[NUM_SENSORS] = {false, false, false, false};

// Data object to store sensor data
Data data = Data();

// Utilities - HeartBeat flashes the built in led every 500ms to let you know the microcontroller has not gotten stuck
HeartBeat heartBeat = HeartBeat(LED_BUILTIN);

void setup() {
  Serial.begin(115200);
  for(int i = 0; i < NUM_SENSORS; i ++) {
    pSensors[i].begin();
    ledModules[i].begin();
  }
  heartBeat.begin();
  audioOut.begin();
  pinMode(HEARTLED, OUTPUT);
}

void loop() {
  heartBeat.update();
  // get inputs from reedswitch sensors
  for(int i = 0; i < NUM_SENSORS; i ++) {
    pSensors[i].update();
    ledModules[i].update();
  }
  
  // updates data for each section
  for(int i = 0; i < NUM_SENSORS; i ++ ) {
    int c = pSensors[i].countMagnets();
    data.setCount(i, c);
    #ifdef DEBUG
      if(data.changed(i)) {
        Serial.print("Data changed in section: ");
        Serial.print(i);
        Serial.print("Count: ");
        Serial.println(c);
      }
    #endif
  }

  // Check all what is inserted in each slot
  for(int i = 0; i < NUM_SENSORS; i ++) {
    if(data.changed(i)) {
      int cp1 = correctPucks[i][0];
      int cp2 = correctPucks[i][1];
       
      // Trigger fade outs on a detected puck remove
      if (data.lastCount(i) == cp1 ) {
        ledModules[i].triggerFadeOut1();
        #ifdef DEBUG
          Serial.print("Section: "); Serial.print(i);
          Serial.println(" Fade out1 Triggered");
        #endif
      }
      else if (data.lastCount(i) == cp2 ) {
        ledModules[i].triggerFadeOut2();
        #ifdef DEBUG
          Serial.print("Section: "); Serial.print(i);
          Serial.println(" Fade out2 Triggered");
        #endif
      } 

        // play remove sound when the count is 0 and the sensor has not seen any change in the cooldown timer window
        if(data.count(i) == 0 && removeCooldownTimers[i] == 0) {
          audioOut.playTrack(4); //puck removed
          // clear slot state to false if puck is removed
          libbrechtInSlots[i] = false;
          bentleyInSlots[i] = false;
        }

        // play insert sound when the sensors detect a count greater than zero and last count was zero and its cooled down
        if(data.lastCount(i) == 0 && data.count(i) > 0 && successCooldownTimers[i] == 0) {
          audioOut.playTrack(3); //play forward audio insert track
        }

      // update cooldown timers because a change in magnet count has been detected
      if(data.count(i) > 0) {
        successCooldownTimers[i] = millis();
      }

    } // end data changed

    for(int i = 0; i < NUM_SENSORS; i ++) {
      if(successCooldownTimers[i] != 0) {
        if(millis() - successCooldownTimers[i] >= PUCK_COOLDOWN) {
          int cp1 = correctPucks[i][0];
          int cp2 = correctPucks[i][1];
          if(data.count(i) == cp1) {
            audioOut.playTrack(5+i); 
            ledModules[i].triggerFadeIn1();
            libbrechtInSlots[i] = true;

            // Play achievement audio
            bool playAchievement = true;
            for(int j = 0; j < NUM_SENSORS; j ++) {
              if(libbrechtInSlots[j] == false)
                playAchievement = false;
            }
            if(playAchievement)
              audioOut.playTrack(1);
            // end play achievement

            #ifdef DEBUG
              Serial.print("Section: "); Serial.print(i);
              Serial.println(" FadeIn1 Triggered");
            #endif
          } else if (data.count(i) == cp2) {
            audioOut.playTrack(5+i); 
            ledModules[i].triggerFadeIn2();
            bentleyInSlots[i] = true;
            // Play achievement audio
            bool playAchievement = true;
            for(int j = 0; j < NUM_SENSORS; j ++) {
              if(bentleyInSlots[j] == false)
                playAchievement = false;
            }
            if(playAchievement)
              audioOut.playTrack(2);
            // end play achievement
            #ifdef DEBUG
              Serial.print("Section: "); Serial.print(i);
              Serial.println(" FadeIn2 Triggered");
            #endif
          }
          // turn of the timer
          successCooldownTimers[i] = 0;
        } 
      } // end if successCooldownTimers

      // reset cool down for the remove sound
      if(removeCooldownTimers[i] != 0) {
        if(millis() - removeCooldownTimers[i] >= PUCK_COOLDOWN) {
          removeCooldownTimers[i] = 0;
        }
      }
    } // end cooldownTimers check

  }
}

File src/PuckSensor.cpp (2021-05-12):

#include "PuckSensor.h"

PuckSensor::PuckSensor(uint8_t ser, uint8_t clk, uint8_t shld) {
  mSer = ser;
  mClk = clk;
  mShld = shld;
  mTimer = 0;
}
void PuckSensor::begin() {
  // Should be called from the Arduino setup function
  pinMode(mSer, OUTPUT);
  pinMode(mClk, OUTPUT);
  pinMode(mShld, OUTPUT);
}
void PuckSensor::update() {
  if(millis() - mTimer > mTimeStep) {
    // Write pulse to load pin
    digitalWrite(mShld, LOW); // Enables the parallel inputs
    delayMicroseconds(5);
    digitalWrite(mShld, HIGH); // Inhibits parallel inputs
    delayMicroseconds(5);
    // Read the two bytes from the the shift registers
    reedData[0] = myShiftIn(mSer, mClk, LSBFIRST);
    reedData[1] = myShiftIn(mSer, mClk, LSBFIRST);
    mTimer = millis();
  }
}

uint8_t PuckSensor::myShiftIn(uint8_t dataPin, uint8_t clockPin, uint8_t bitOrder) {
  uint8_t value = 0;
  uint8_t i;
  for (i = 0; i < 8; ++i) {
    digitalWrite(clockPin, LOW);
    if (bitOrder == LSBFIRST)
      value |= digitalRead(dataPin) << i;
    else
      value |= digitalRead(dataPin) << (7 - i);
    digitalWrite(clockPin, HIGH);
  }
  return value;
}
int PuckSensor::countMagnets() {
  // count the number of magnets the reed switches detect
  int numMagnets = 0;
  // byte 1
  int numBytes = 2;
  byte b;
  for(int bi = 0; bi < numBytes; bi ++) {
      b = reedData[bi];
      for(int i = 0; i < 8; i++) {
          if (b & B00000001) numMagnets ++;
          b = b>>1; // bit shift the bits in b one to the right
      }
  }
  return numMagnets;
}

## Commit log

2021-05-03 very basic senseing of a 2 magnet on 1 puckSensor. Lights up Leds too
2021-08-02 Basic MVP audio is working well. Retrigger delay timers are in place
2021-08-25 Added in all the docs, pictures, eagle, assets, into this repo
    [Adafruit NeoPixel Ring 24 B - Holder 4.brd, Adafruit NeoPixel Ring 24 B - Holder 4.sch, Nakaya BOM v0.xls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]
2022-06-16 updated docs, added tech manual, removed duplicate info
    [Nakaya BOM v0.xls, Nakaya BOM v2.xls, Nakaya BOM.xls]

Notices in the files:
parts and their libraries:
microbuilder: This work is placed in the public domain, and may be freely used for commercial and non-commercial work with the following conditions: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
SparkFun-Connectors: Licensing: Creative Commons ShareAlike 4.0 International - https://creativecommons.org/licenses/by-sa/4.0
